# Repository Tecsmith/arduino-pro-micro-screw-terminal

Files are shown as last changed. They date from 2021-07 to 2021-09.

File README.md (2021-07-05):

# Screw terminal board for Pro-Micro boards

| Board | URL |
|---|---|
| [Pro Micro Screw Terminal Breakout](https://tecsmith.github.io/arduino-pro-micro-screw-terminal/) |  [`c1k.it/pro1`](http://c1k.it/pro1) |

## Help, About, *etc.*

Refer to the [docs folder](docs/index.md).

<p align="center" style="color:#069">★</p>

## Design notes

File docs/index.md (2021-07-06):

# Pro Micro / Pro Mini Screw Terminal Breakout

**Pro Micro Screw Terminal Breakout**, for mounting "Pro Micro" boards.

GitHub repository at [Tecsmith/arduino-pro-micro-screw-terminal](https://github.com/Tecsmith/arduino-pro-micro-screw-terminal)

----------

## Features & Specifications

- Simple breakout in the Qwiic board form factor exposing Pro Micro / Pro Mini pins to screw terminals
- Supports many "pro micro" based boards, e.g.:
  - Sparkfun [Pro Micro](https://www.sparkfun.com/products/12587)
  - Zio [ZUINO XS PSYFI32](https://www.smart-prototyping.com/Zuino-XS-PsyFi32.html)
  - Arduino [Pro Mini](https://store.arduino.cc/usa/arduino-pro-mini) <small style="color:red">{*RETIRED*}</small>
  - April Brother [Cactus Micro](https://wiki.aprbrother.com/en/Cactus_Micro_Rev2.html) <small style="color:red">{*RETIRED*}</small>
- 2x Qwiic connectors (works with SparkFun's [Qwiic Connect System](https://www.sparkfun.com/qwiic))
- Standard I<sup>2</sup>C breakout pins
- Remote reset button via JST-PH-2 header

----------

## On Board Jumpers

### JP1, JP2 & JP3

- For use with the retired Arduino Pro Mini.  Refer to the schematic for use.

### JP4 - I<sup>2</sup>C Pull Ups (top)

- Connected _(default)_: 4.7KΩ pullups
- Cut both sides: No pullups

### JP5 - LED Enable (top)

- Connected _(default)_: LED shows power state
- Cut: LED disabled

----------

## Manufacturing
-------------

* Schematic print: [pro-micro-screw-terminal-v1.0.pdf](pro-micro-screw-terminal-v1.0.pdf)
* Schematic source (in EAGLE): [Tecsmith/arduino-pro-micro-screw-terminal/EAGLE/pro-micro-screw-terminal-v1.0.sch](https://github.com/Tecsmith/arduino-pro-micro-screw-terminal/blob/main/EAGLE/pro-micro-screw-terminal-v1.0.sch)
* PCB design (in EAGLE): [Tecsmith/arduino-pro-micro-screw-terminal/EAGLE/pro-micro-screw-terminal-v1.0.brd](https://github.com/Tecsmith/arduino-pro-micro-screw-terminal/blob/main/EAGLE/pro-micro-screw-terminal-v1.0.brd)

| Top | Bottom |
|:---:|:---:|
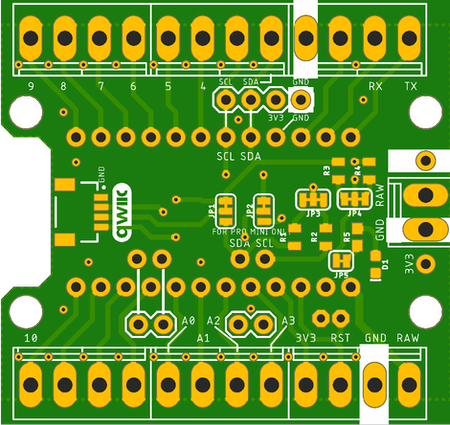
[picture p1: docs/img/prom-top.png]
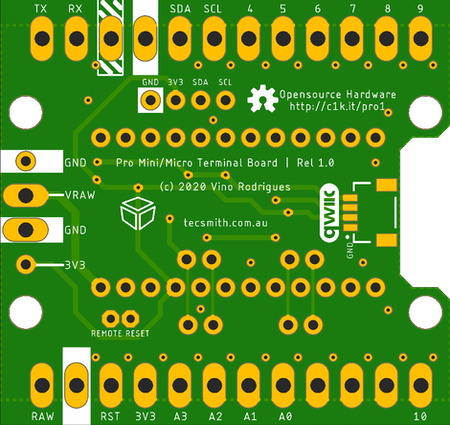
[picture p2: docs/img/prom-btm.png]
|  |  |

<p align="center">Initial prototype built by JCLPCB</p>

----------
<p align="center" style="color:#069">★</p>

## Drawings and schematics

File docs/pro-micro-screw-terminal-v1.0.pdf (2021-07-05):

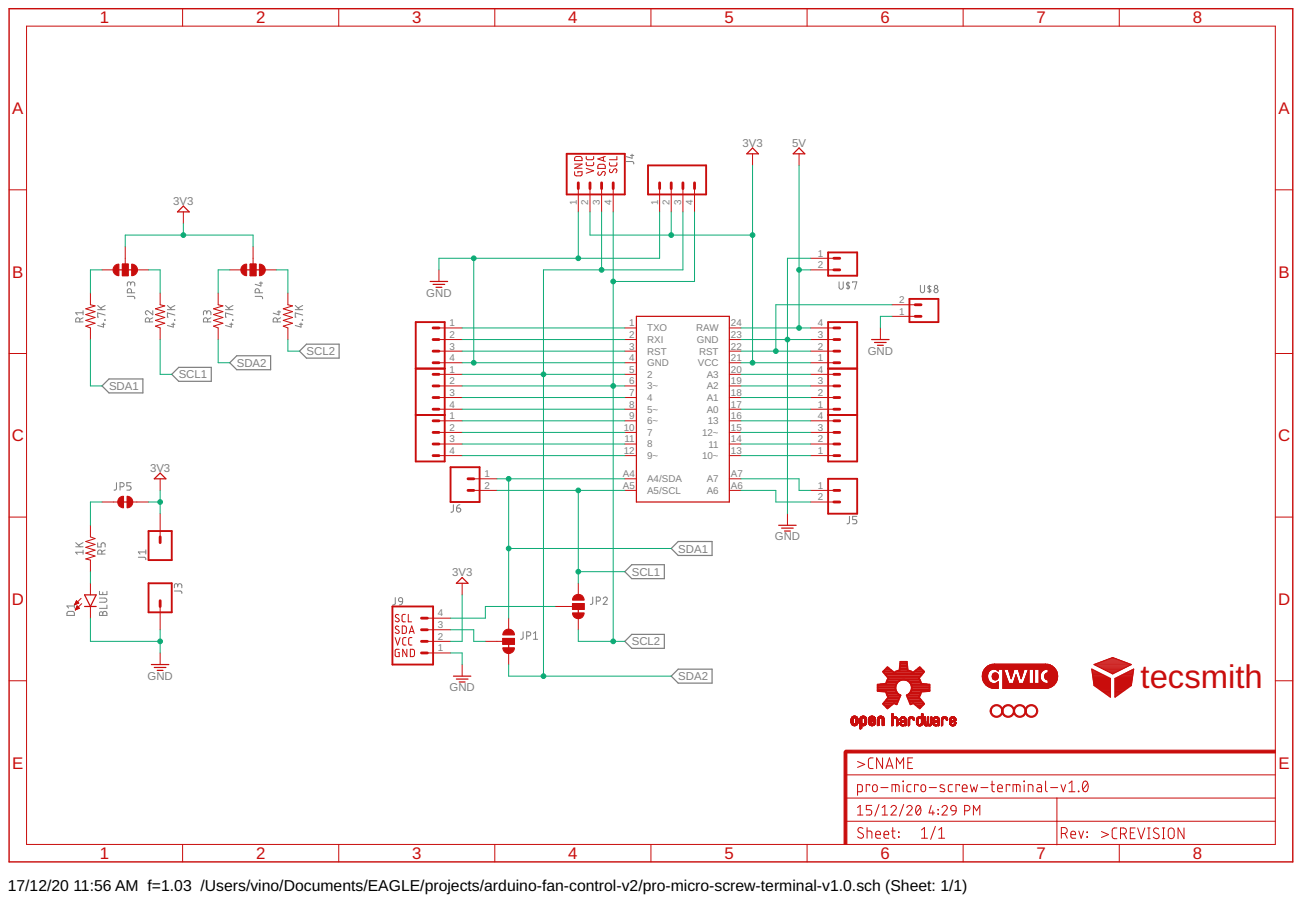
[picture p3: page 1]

2 | 10
3 | 11

17/12/20 11:56 AM f=1.03 /Users/vino/Documents/EAGLE/projects/arduino-fan-control-v2/pro-micro-screw-terminal-v1.0.sch (Sheet: 1/1)

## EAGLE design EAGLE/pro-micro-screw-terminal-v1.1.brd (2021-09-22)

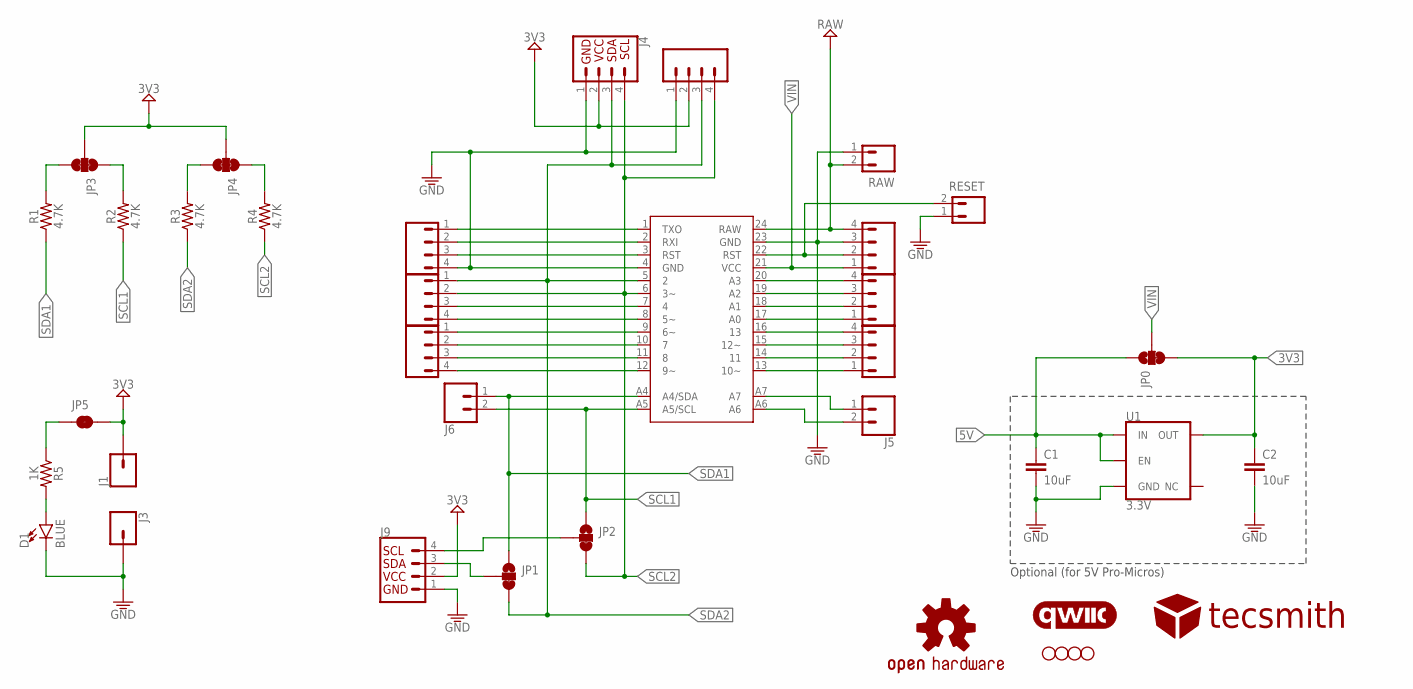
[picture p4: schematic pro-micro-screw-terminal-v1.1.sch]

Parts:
B1: ARDUINO_PRO_MININO_FTDI; ARDUINO_PRO_MINI
C1, C2: 10uF; 0603
D1: BLUE; LED-0603
H1, H2, H5, H6: STAND-OFF
J1, J3: CONN_01PTH_NO_SILK_YES_STOP; 1X01_NO_SILK
J2: CONN_04PTH; 1X04
J4, J9: QWIIC_RIGHT_ANGLE; JST04_1MM_RA
J5, J6: CONN_02; 1X02
JP0, JP1, JP2: JUMPER-SMT_3_1-NC_TRACE_SILK; SMT-JUMPER_3_1-NC_TRACE_SILK
JP3, JP4: JUMPER-SMT_3_2-NC_TRACE_SILK; SMT-JUMPER_3_2-NC_TRACE_SILK
JP5: JUMPER-SMT_2_NC_TRACE_SILK; SMT-JUMPER_2_NC_TRACE_SILK
LOGO1: OSHW-LOGOS; OSHW-LOGO-S
LOGO2: QWIIC_LOGO_6MM; QWIIC_6MM
R1, R2, R3, R4: 4.7K; 0805
R5: 1K; 0603
RAW: CON_02SCREW; WURTH_2431_3.5MM_2X_SCREW
RESET: JST-PH-2NS; JST-PH2-NO-SILK
U1: 3.3V; SOT23-5
U$1, U$2, U$3, U$4, U$5, U$6: CON_04SCREW; WURTH_2431_3.5MM_4X_SCREW
U$9: TECSMITH-LOGO

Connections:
3V3: C2.1, J1.1, J2.2, J4.2, J9.2, JP0.3, JP3.2, JP4.2, JP5.2, U1.5 (OUT)
5V: C1.1, JP0.1, U1.1 (IN), U1.3 (EN)
GND: B1.4 (GND), B1.23 (GND), C1.2, C2.2, D1.C, J2.1, J3.1, J4.1, J9.1, RAW.1, RESET.1, U1.2 (GND), U$1.4, U$6.3
unnamed: B1.1 (TXO), U$1.1
unnamed: B1.2 (RXI), U$1.2
unnamed: B1.3 (RST), U$1.3
unnamed: B1.A7, J5.1
unnamed: B1.A6, J5.2
unnamed: D1.A, R5.2
unnamed: B1.7 (4), U$2.3
unnamed: B1.8 (5~), U$2.4
unnamed: B1.9 (6~), U$3.1
unnamed: B1.10 (7), U$3.2
unnamed: B1.11 (8), U$3.3
unnamed: B1.12 (9~), U$3.4
unnamed: JP5.1, R5.1
unnamed: B1.22 (RST), RESET.2, U$6.2
unnamed: JP3.1, R2.2
unnamed: B1.20 (A3), U$5.4
unnamed: B1.19 (A2), U$5.3
unnamed: B1.18 (A1), U$5.2
unnamed: B1.17 (A0), U$5.1
unnamed: B1.16 (13), U$4.4
unnamed: B1.15 (12~), U$4.3
unnamed: B1.14 (11), U$4.2
unnamed: B1.13 (10~), U$4.1
unnamed: JP3.3, R1.2
unnamed: JP4.3, R3.2
unnamed: JP4.1, R4.2
RAW: B1.24 (RAW), RAW.2, U$6.4
SCL: J9.4, JP2.2
SCL1: B1.A5 (A5/SCL), J6.2, JP2.1, R2.1
SCL2: B1.6 (3~), J2.4, J4.4, JP2.3, R4.1, U$2.2
SDA: J9.3, JP1.2
SDA1: B1.A4 (A4/SDA), J6.1, JP1.1, R1.1
SDA2: B1.5 (2), J2.3, J4.3, JP1.3, R3.1, U$2.1
VIN: B1.21 (VCC), JP0.2, U$6.1

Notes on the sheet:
Optional (for 5V Pro-Micros)

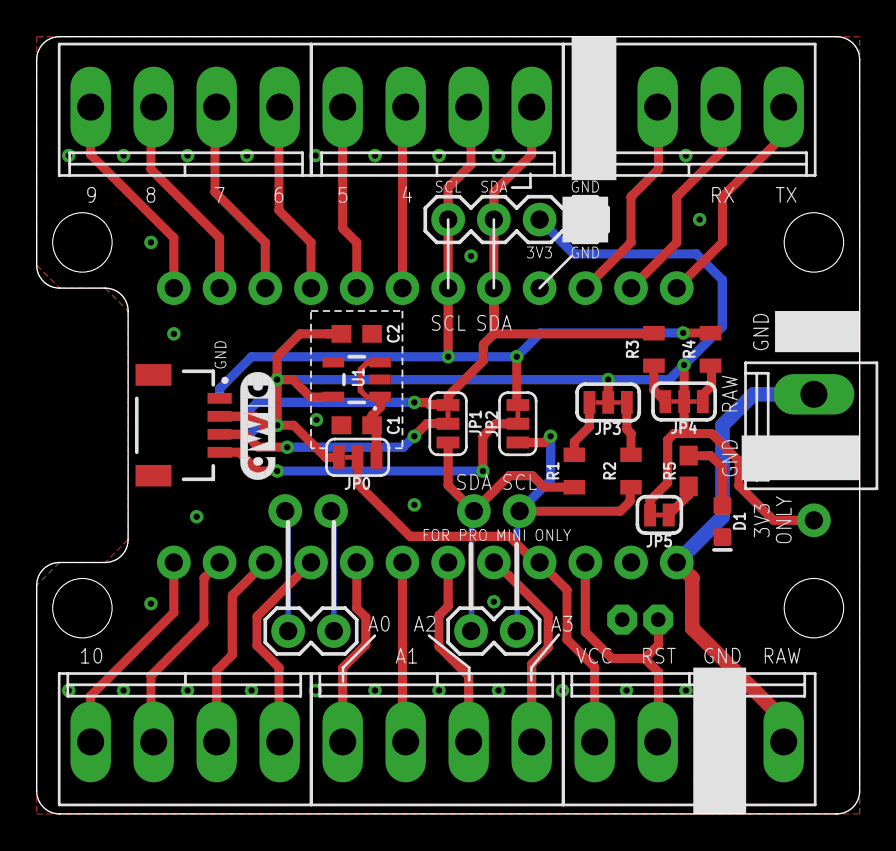
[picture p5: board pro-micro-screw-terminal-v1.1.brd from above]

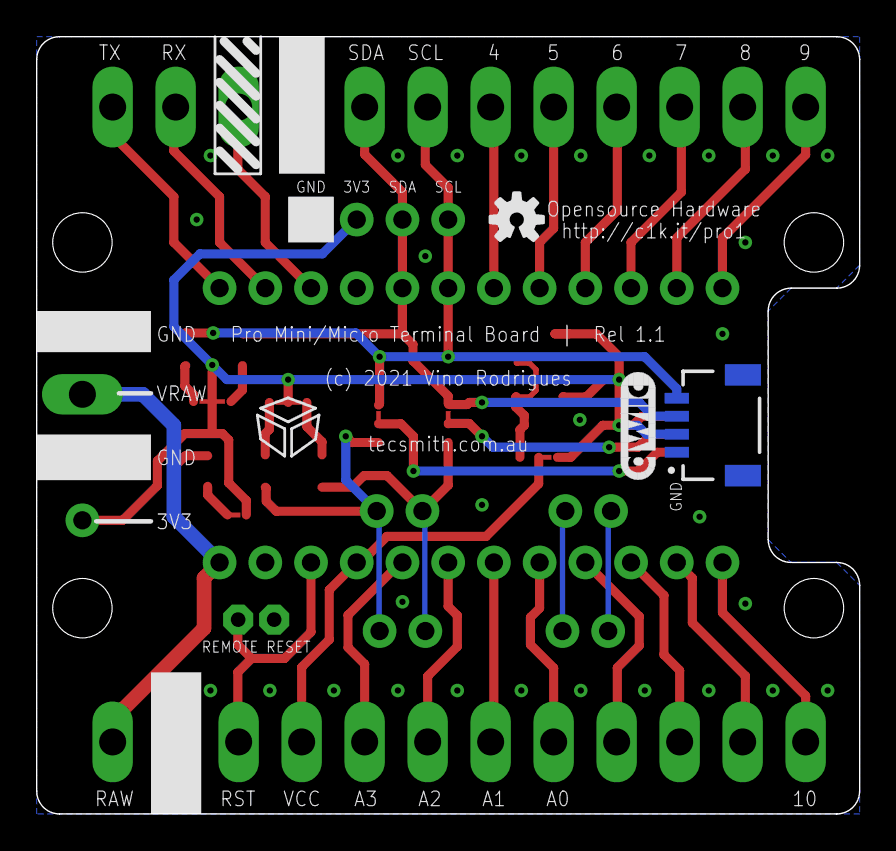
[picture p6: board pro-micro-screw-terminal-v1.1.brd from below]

Board: 2 copper layers, 45.7 x 43.2 mm, 39 parts (4 on the bottom side), 37 nets.

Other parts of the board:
LOGO3: QWIIC_LOGO_6MM; QWIIC_6MM

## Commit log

2021-07-04 moved from fan-control project
    [pro-micro-screw-terminal-v1.0.brd, pro-micro-screw-terminal-v1.0.sch]
2021-07-05 move items from arduino-fan-control-v2 project
2021-09-22 v1.1 add a V/Reg to account for the new Qwiic Pro Micro USB-C that uses a 5v VCC, but a 3v3 qwiic bus
    [pro-micro-screw-terminal-v1.1.brd, pro-micro-screw-terminal-v1.1.sch]

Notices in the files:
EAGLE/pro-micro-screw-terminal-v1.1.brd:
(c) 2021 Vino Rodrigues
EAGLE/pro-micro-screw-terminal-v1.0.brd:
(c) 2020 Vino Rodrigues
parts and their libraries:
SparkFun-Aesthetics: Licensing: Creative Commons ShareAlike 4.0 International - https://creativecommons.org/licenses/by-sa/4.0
